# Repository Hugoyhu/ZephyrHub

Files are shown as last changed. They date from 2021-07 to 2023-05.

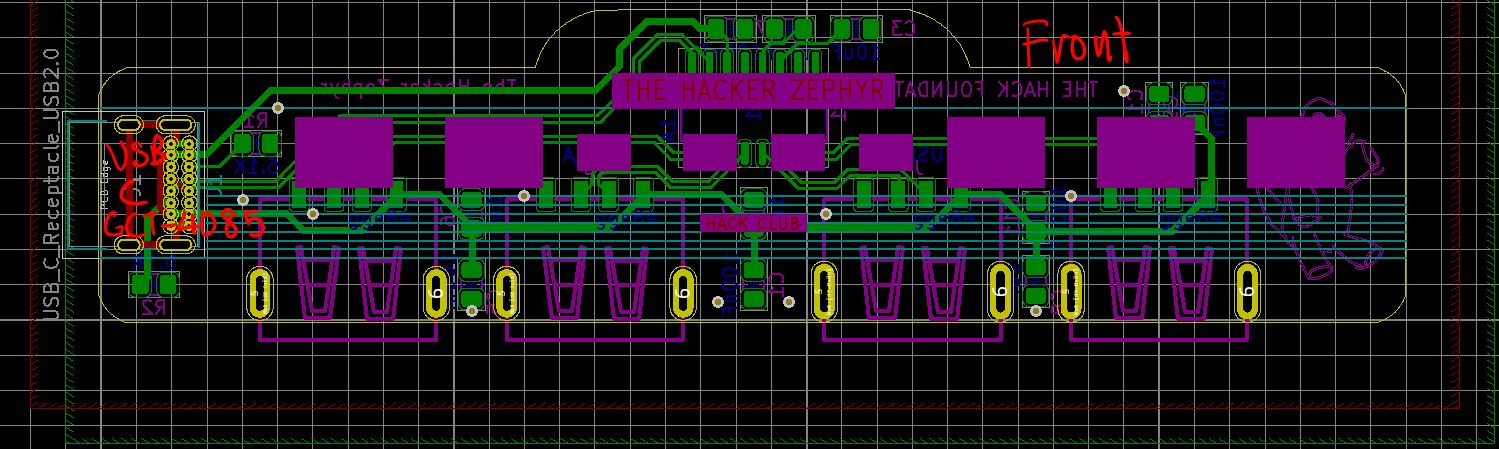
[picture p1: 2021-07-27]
assembly instructions front.JPG

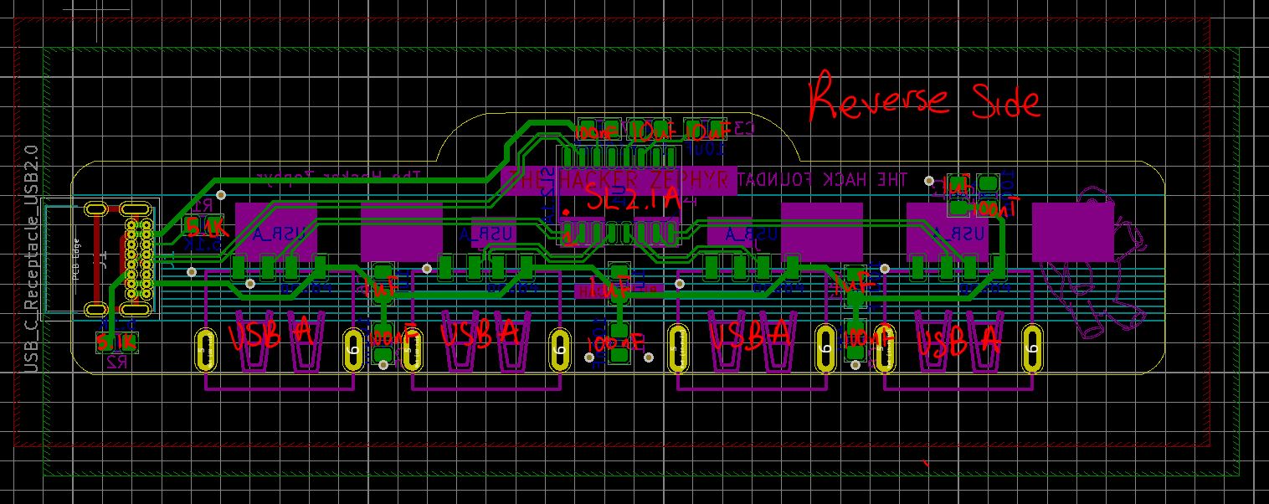
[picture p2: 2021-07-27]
assembly instructions reverse.JPG

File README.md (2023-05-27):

# ZephyrHub

ZephyrHub is a simple four port USB 2.0 Hub designed for the [Hacker Zephyr](https://zephyr.hackclub.com), a 10-day hackathon where hack clubbers went across the country from HC HQ in Shelburne VT to SpaceX in LA.

The board is modeled off the Superdome, one of the train cars chartered for the journey. It allows for a reversible USB2/3 Type C cable in, and outputs four USB2 Type A ports. 

Front of ZephyrHub held up

The design files, schematic, and BOM/ordering info are available in this repo. Files were designed in KiCAD v5 and are forward-compatible to KiCAD v6+. An image of the schematic and a .zip of the gerbers are also provided.

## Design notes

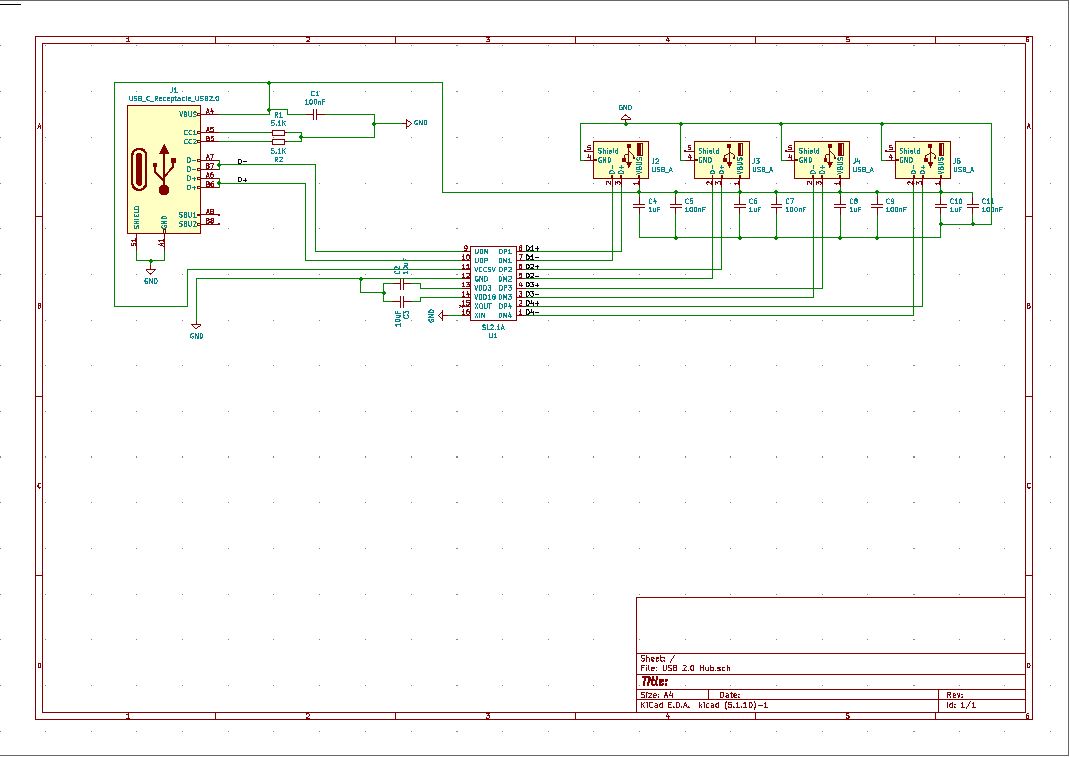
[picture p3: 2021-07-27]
usb-2.0-hub-schematic.JPG

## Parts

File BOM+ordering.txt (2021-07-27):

BOM:

4x USB A connectors; LCSC; https://lcsc.com/product-detail/USB-Connectors_Jing-Extension-of-the-Electronic-Co-910-151A2022S10100_C39429.html
1x SL2.1A; LCSC; https://lcsc.com/product-detail/USB-ICs_CoreChips-SL2-1A_C192893.html
1x GCT USB-4085; Mouser; https://www.mouser.com/ProductDetail/GCT/USB4085-GF-A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
2x 5.1K 0805 Resistor; Generic
2x 10uF 0805 MLCC Capacitor; Generic
4x 1uF 0805 MLCC Capacitor; Generic
5x 100nF 0805 MLCC Capacitor; Generic

Ordering information:

1.2mm FR-4 PCB, double sided, 1oz copper, Matte Black Soldermask, ENIG finish, 94.18mm x 22.54mm

Please use RoHS compliant parts, PCBs, and equipment.

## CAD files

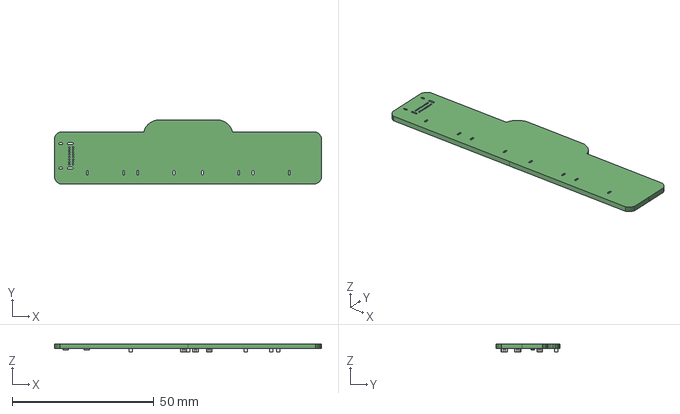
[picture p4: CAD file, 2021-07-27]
USB 2.0 Hub.step
94.2 x 22.5 x 2.90 mm

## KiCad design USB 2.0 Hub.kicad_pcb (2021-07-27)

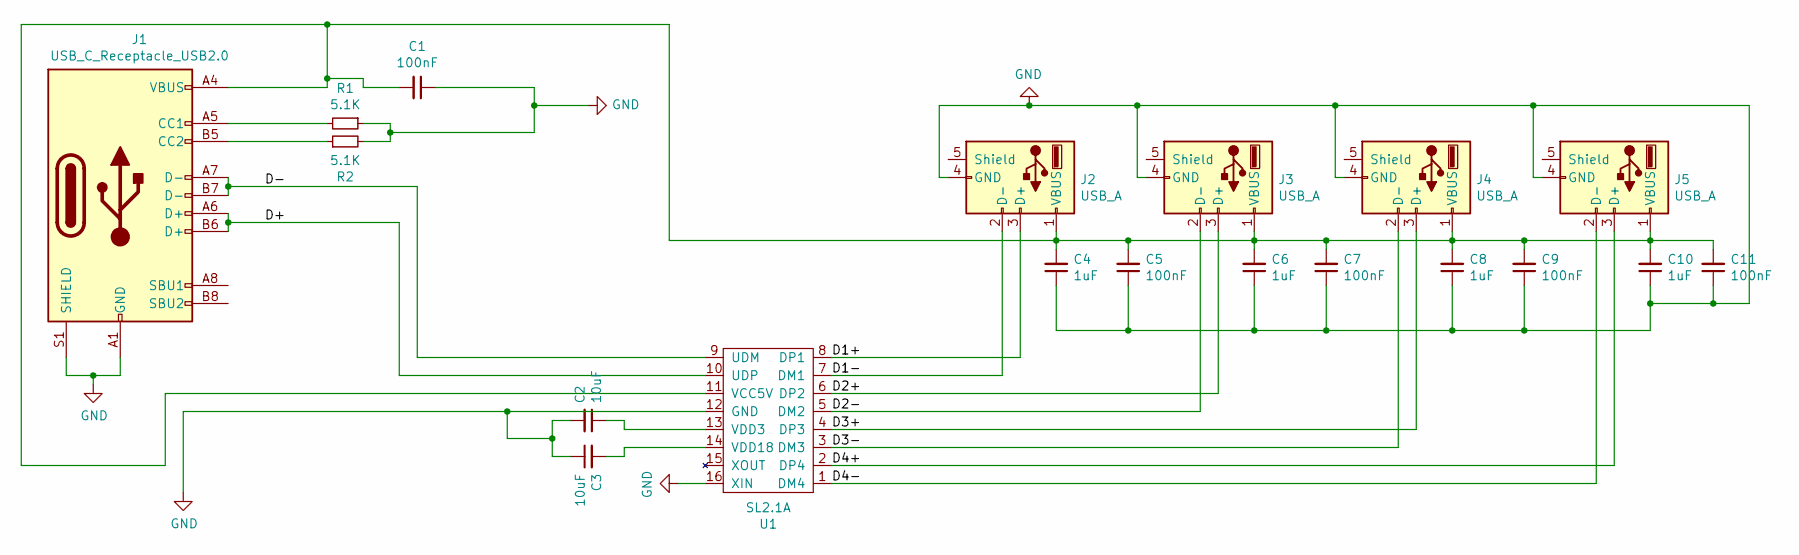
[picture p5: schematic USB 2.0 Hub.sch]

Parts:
C1, C5, C7, C9, C11: 100nF; C_0805_2012Metric_Pad1.18x1.45mm_HandSolder
C2, C3: 10uF; C_0805_2012Metric_Pad1.18x1.45mm_HandSolder
C4, C6, C8, C10: 1uF; C_0805_2012Metric_Pad1.18x1.45mm_HandSolder
J1: USB_C_Receptacle_USB2.0; USB_C_Receptacle_GCT_USB4085
J2, J3, J4, J5: USB_A; USBA_THT_SMD
R1, R2: 5.1K; R_0805_2012Metric_Pad1.20x1.40mm_HandSolder
U1: SL2.1A; SOIC-16_4.55x10.3mm_P1.27mm

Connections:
/D1+: J2.3 (D+), U1.8 (DP1)
/D1-: J2.2 (D-), U1.7 (DM1)
/D2+: J3.3 (D+), U1.6 (DP2)
/D2-: J3.2 (D-), U1.5 (DM2)
/D3+: J4.3 (D+), U1.4 (DP3)
/D3-: J4.2 (D-), U1.3 (DM3)
/D4+: J5.3 (D+), U1.2 (DP4)
/D4-: J5.2 (D-), U1.1 (DM4)
/D+: J1.A6 (D+), J1.B6 (D+), U1.10 (UDP)
/D-: J1.A7 (D-), J1.B7 (D-), U1.9 (UDM)
GND: C1.1, C2.2, C3.1, C4.1, C5.1, C6.1, C7.1, C8.1, C9.1, C10.1, C11.1, J1.A1 (GND), J1.A12 (GND), J1.B1 (GND), J1.B12 (GND), J1.S1 (SHIELD), J2.4 (GND), J3.4 (GND), J4.4 (GND), J5.4 (GND), R1.1, R2.2, U1.12 (GND), U1.16 (XIN)
unnamed: C1.2, C4.2, C5.2, C6.2, C7.2, C8.2, C9.2, C10.2, C11.2, J1.A4 (VBUS), J1.A9 (VBUS), J1.B4 (VBUS), J1.B9 (VBUS), J2.1 (VBUS), J3.1 (VBUS), J4.1 (VBUS), J5.1 (VBUS), U1.11 (VCC5V)
unnamed: C2.1, U1.13 (VDD3)
unnamed: C3.2, U1.14 (VDD18)
unnamed: J1.A5 (CC1), R1.2
unnamed: J1.B5 (CC2), R2.1

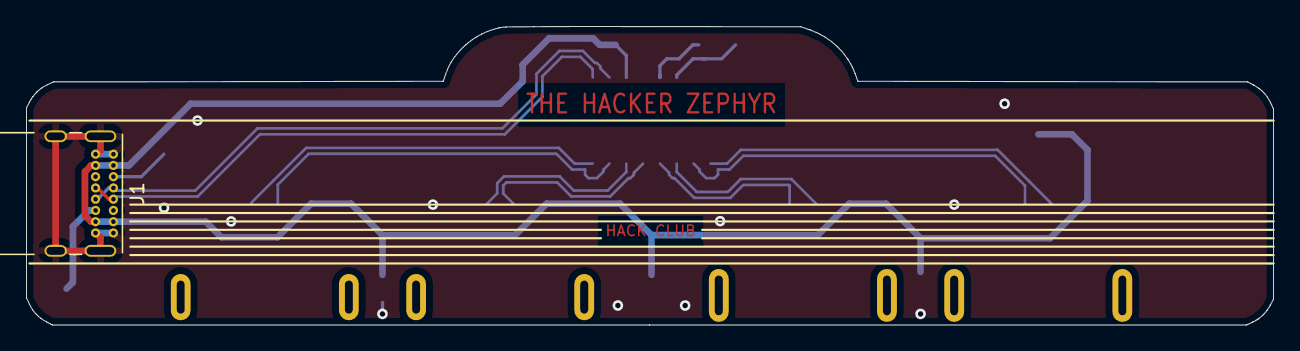
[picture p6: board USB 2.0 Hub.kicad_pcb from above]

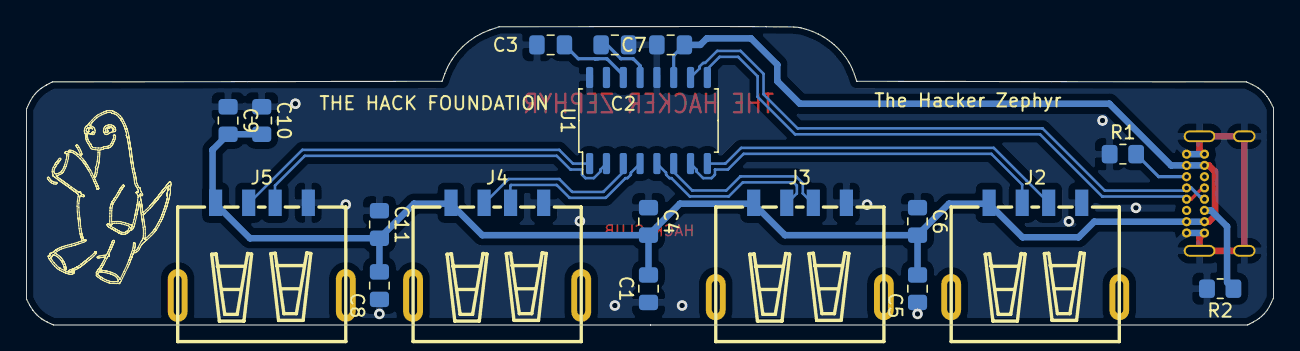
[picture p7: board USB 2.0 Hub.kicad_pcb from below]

Board: 2 copper layers, 94.2 x 22.5 mm, 19 parts (18 on the bottom side), 16 nets.
